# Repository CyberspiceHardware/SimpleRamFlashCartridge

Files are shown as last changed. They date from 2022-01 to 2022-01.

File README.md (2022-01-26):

# Simple Ram Flash Cartridge 

This is a simple ROM/RAM/Flash cartridge for a BBC Master or Acorn Electron.

It takes a single 32K memory device. For example an AS6C62256 or a AT28C256.

# Jumpers / Links

There are three jumpers

J2 - This selects whether the cartridge is for the Master or Electron. It selects the R/WR source from the edge connector.
J3 - This selects whether pin 27 is A14 or nWE. It is typically A14 for (E(P))ROM but nWE for SRAM or Flash.
J4 - This selects whether pin 1 is A14 or 5V. It is typically A14 for SRAM or Flash and 5V (VPP) for (E(P))ROM

You may omit J3 if you want to use a 27C128 EPROM chip where pin 27 is the nPGM pin.

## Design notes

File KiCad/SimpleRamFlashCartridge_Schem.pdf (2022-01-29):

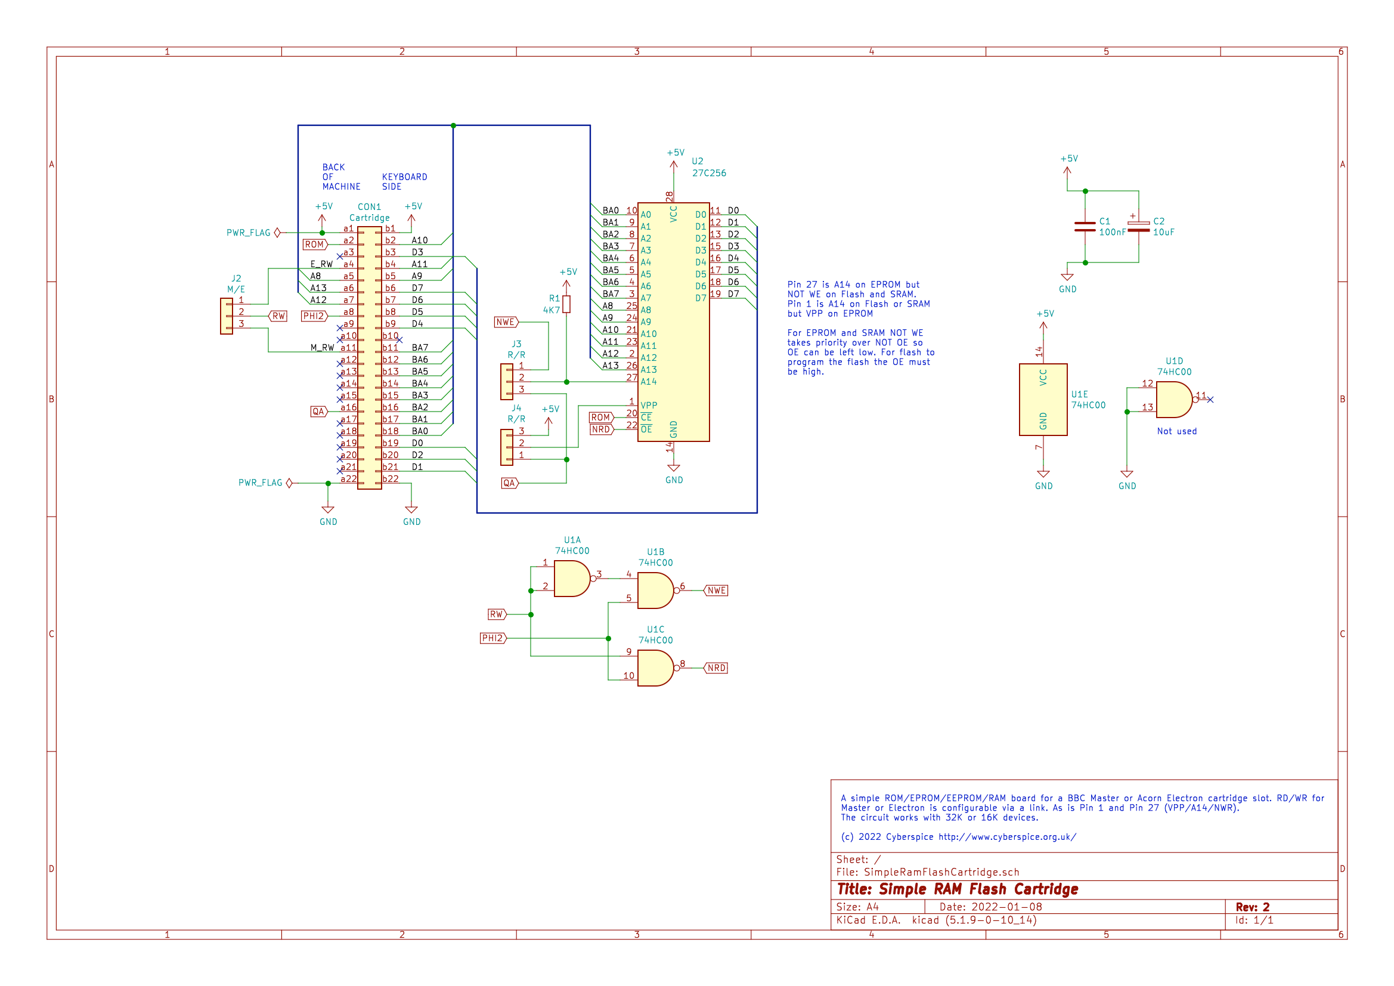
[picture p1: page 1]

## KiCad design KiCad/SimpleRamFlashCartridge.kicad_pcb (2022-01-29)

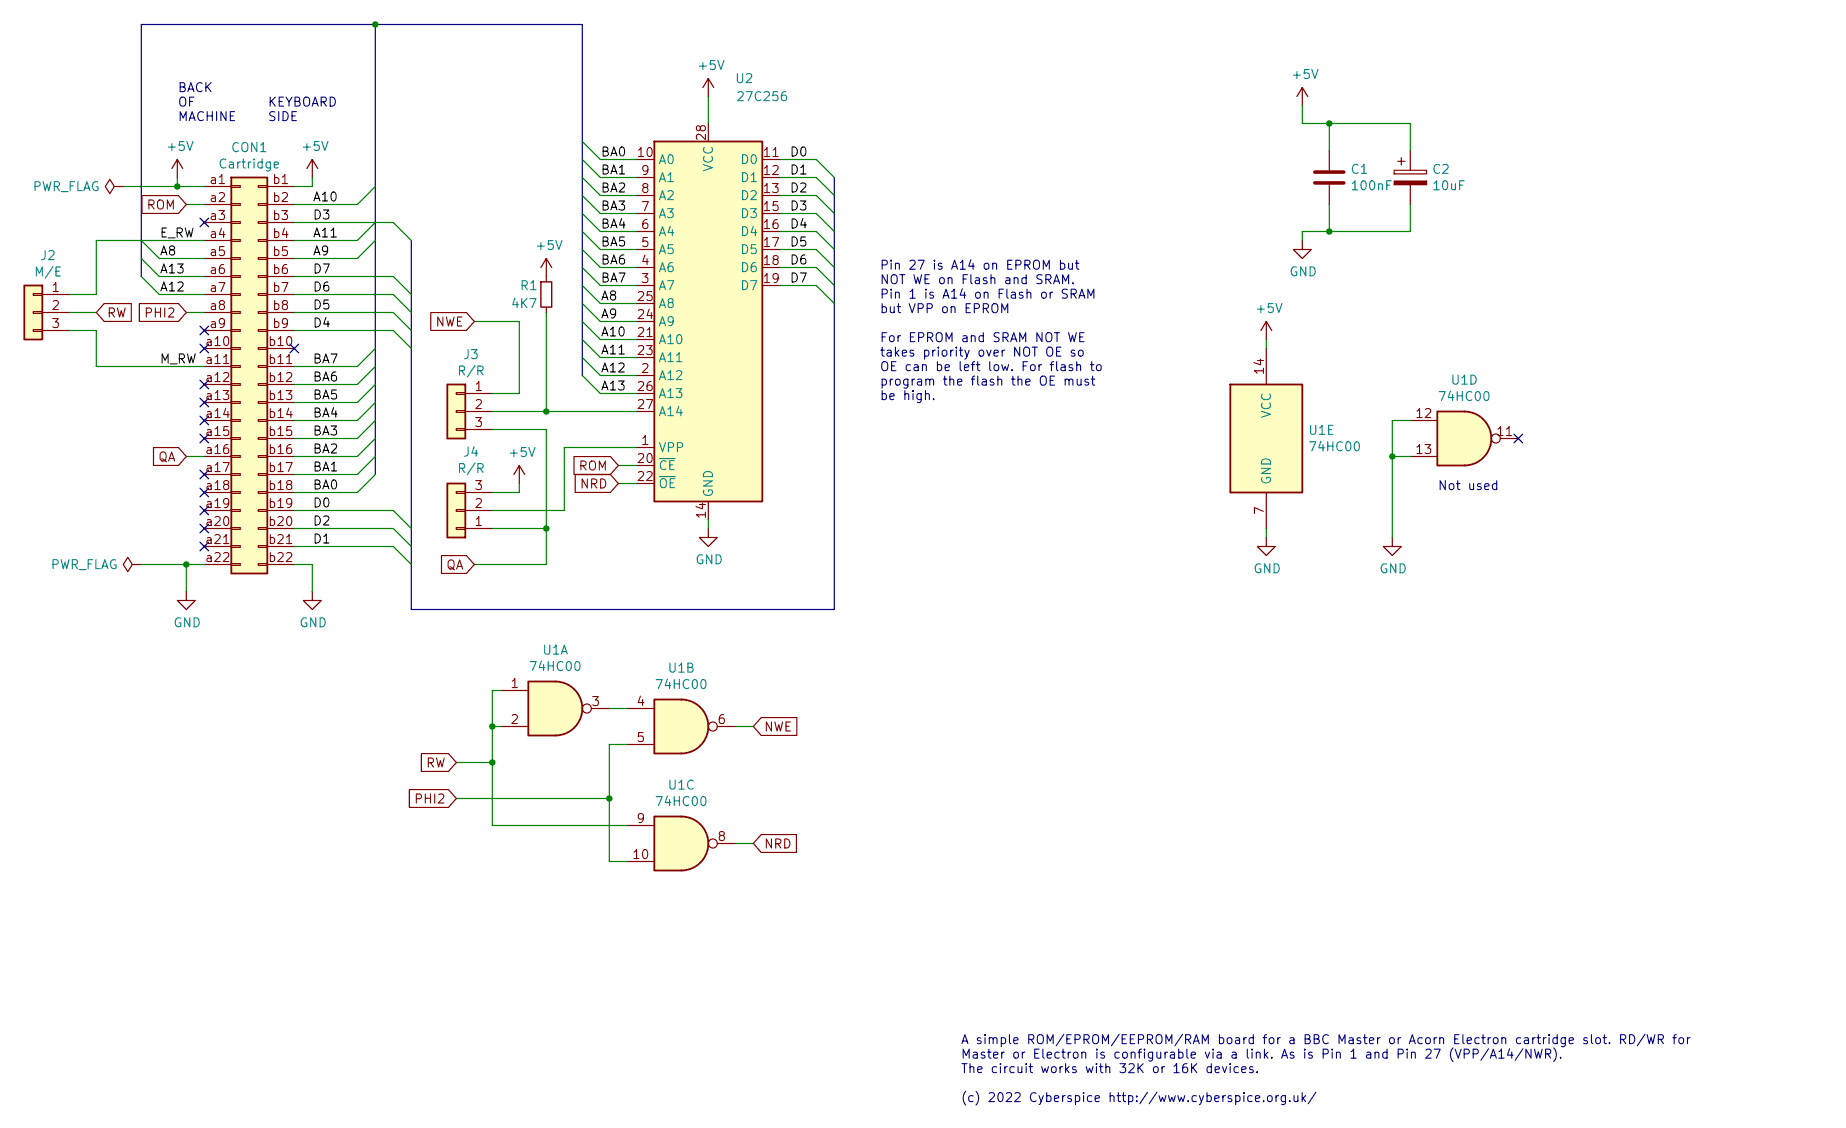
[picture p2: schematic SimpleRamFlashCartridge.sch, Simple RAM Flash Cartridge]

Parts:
C1: 100nF; C_Disc_D7.5mm_W2.5mm_P5.00mm
C2: 10uF; CP_Radial_D5.0mm_P2.50mm
CON1: Cartridge; ElectronCartridgeEdge
J2: M/E; PinHeader_1x03_P2.54mm_Vertical
J3, J4: R/R; PinHeader_1x03_P2.54mm_Vertical
R1: 4K7; R_Axial_DIN0204_L3.6mm_D1.6mm_P7.62mm_Horizontal
U1: 74HC00; DIP-14_W7.62mm_Socket
U2: 27C256; DIP-28_W15.24mm_Socket

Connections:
+5V: C1.1, C2.1, CON1.a1, CON1.b1, J4.3, R1.1, U1.14 (VCC), U2.28 (VCC)
/A8: CON1.a5, U2.25 (A8)
/A9: CON1.b5, U2.24 (A9)
/A10: CON1.b2, U2.21 (A10)
/A11: CON1.b4, U2.23 (A11)
/A12: CON1.a7, U2.2 (A12)
/A13: CON1.a6, U2.26 (A13)
/BA0: CON1.b18, U2.10 (A0)
/BA1: CON1.b17, U2.9 (A1)
/BA2: CON1.b16, U2.8 (A2)
/BA3: CON1.b15, U2.7 (A3)
/BA4: CON1.b14, U2.6 (A4)
/BA5: CON1.b13, U2.5 (A5)
/BA6: CON1.b12, U2.4 (A6)
/BA7: CON1.b11, U2.3 (A7)
/D0: CON1.b19, U2.11 (D0)
/D1: CON1.b21, U2.12 (D1)
/D2: CON1.b20, U2.13 (D2)
/D3: CON1.b3, U2.15 (D3)
/D4: CON1.b9, U2.16 (D4)
/D5: CON1.b8, U2.17 (D5)
/D6: CON1.b7, U2.18 (D6)
/D7: CON1.b6, U2.19 (D7)
/E_RW: CON1.a4, J2.1
/M_RW: CON1.a11, J2.3
GND: C1.2, C2.2, CON1.a22, CON1.b22, U1.7 (GND), U1.12, U1.13, U2.14 (GND)
NRD: U1.8, U2.22 (~OE)
NWE: J3.1, U1.6
unnamed: J3.2, R1.2, U2.27 (A14)
unnamed: J4.2, U2.1 (VPP)
unnamed: U1.3, U1.4
PHI2: CON1.a8, U1.5, U1.10
QA: CON1.a16, J3.3, J4.1
ROM: CON1.a2, U2.20 (~CE)
RW: J2.2, U1.1, U1.2, U1.9

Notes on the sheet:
BACK OF MACHINE
KEYBOARD SIDE
Pin 27 is A14 on EPROM but NOT WE on Flash and SRAM. Pin 1 is A14 on Flash or SRAM but VPP on EPROM For EPROM and SRAM NOT WE takes priority over NOT OE so OE can be left low. For flash to program the flash the OE must be high.
Not used
A simple ROM/EPROM/EEPROM/RAM board for a BBC Master or Acorn Electron cartridge slot. RD/WR for Master or Electron is configurable via a link. As is Pin 1 and Pin 27 (VPP/A14/NWR). The circuit works with 32K or 16K devices. (c) 2022 Cyberspice http://www.cyberspice.org.uk/

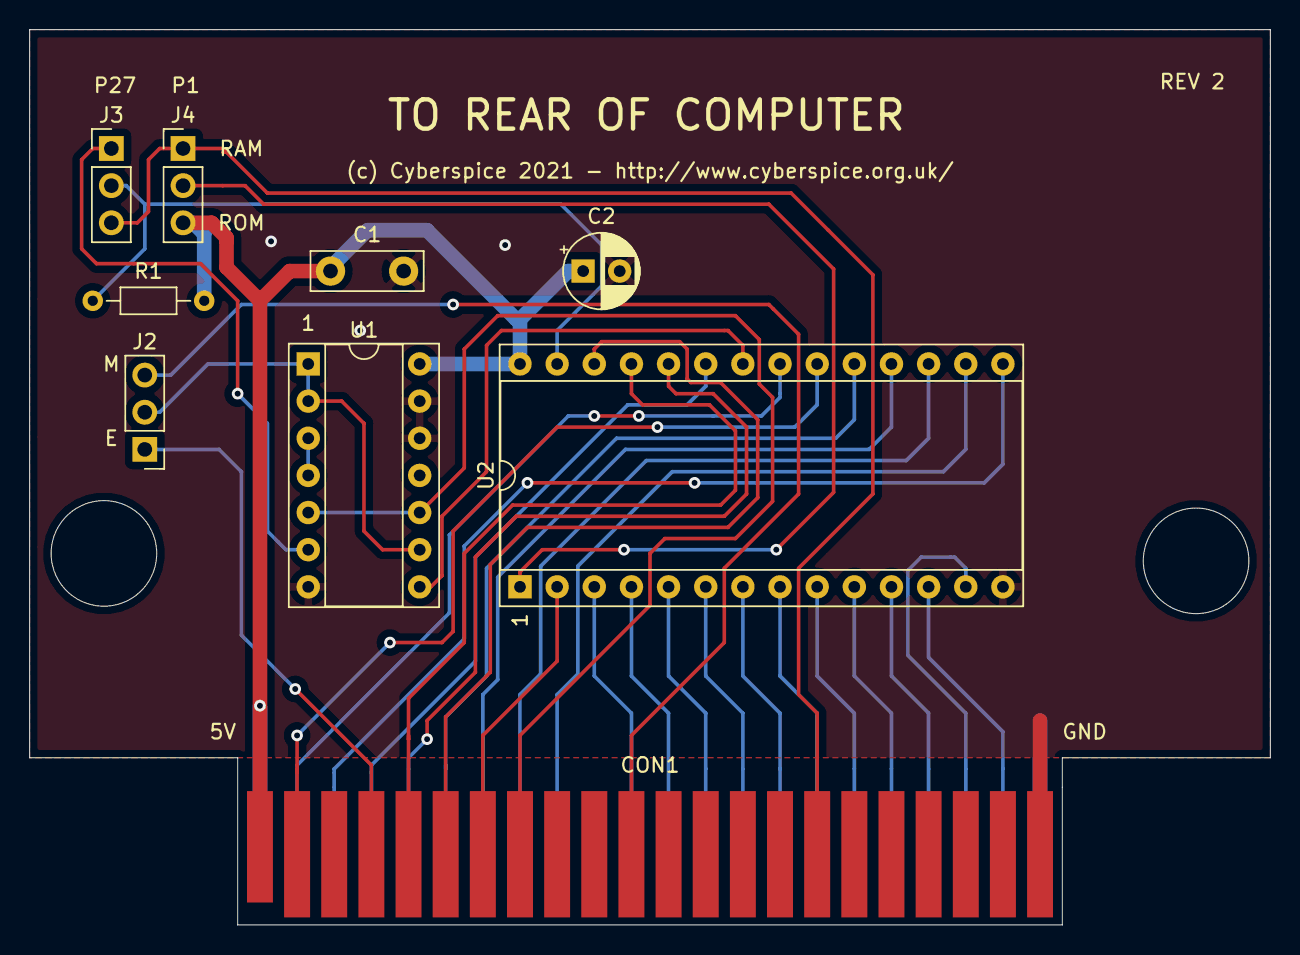
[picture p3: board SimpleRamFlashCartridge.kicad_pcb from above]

Board: 2 copper layers, 84.8 x 61.2 mm, 9 parts (0 on the bottom side), 35 nets.

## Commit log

2022-01-26 Initial version
    [SimpleRamFlashCartridge.kicad_pcb, SimpleRamFlashCartridge.sch]
2022-01-29 Fixed swapping of A10 and A11. Added gerbers and schematics PDF.
    [SimpleRamFlashCartridge-B_Cu.gbr, SimpleRamFlashCartridge-B_Mask.gbr, SimpleRamFlashCartridge-B_Paste.gbr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]
